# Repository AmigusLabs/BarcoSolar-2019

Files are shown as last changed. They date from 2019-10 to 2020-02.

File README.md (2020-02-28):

# BarcoSolar-2019
Barco solar Regata Marine Instruments 2019




Ver proyecto en [Amigus Labs](http://www.amiguslabs.org/portfolio_page/amigus-labs-barco-solar19/)

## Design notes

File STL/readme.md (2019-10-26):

Sec 1 - Soporte No, Relleno 15% — 10:00Horas  240g 

Sec 2 - Soporte Si, Relleno 20% — 19:34Horas  453g

Sec 3 - Soporte No, Relleno 15% — 18:30Horas  340g

Sec 4 - Soporte Si, Relleno 20% — 12:30Horas  268g.

Sec 5 - Soporte Si, Relleno 15% — 11:14Horas  219g

Sec 6 - Soporte NO, Relleno 15% — 13:13Horas  266g 

Sec 7 - Soporte NO, Relleno 15% — 8:05Horas  160g

Sec 8 - Soporte NO, Relleno 15% — 5:15Horas  126g

Sec 9 - Soporte NO, Relleno 15% — 4:45Horas  113g

Sec 10 - Soporte NO, Relleno 15% — 2:36Horas  61g

Soporte Balsas - Soporte No, Relleno 15% — 6:03Horas 146g (total 7:23)

Balsa 1 IZQ- Soporte No, Relleno 15% — 6:04Horas 142g  (total 7:40)

Balsa 2 IZQ- Soporte No, Relleno 15% — 5:34 Horas 127g

Balsa 3 IZQ- Soporte No, Relleno 15% — 1:12Horas 28g

Balsa 1 DER- Soporte No, Relleno 15% — 6:04Horas 142g

Balsa 2 DER- Soporte No, Relleno 15% — 5:37 Horas 127g

Balsa 3 DER- Soporte No, Relleno 15% — 1:12Horas 28g

Aletas - Soporte No, Relleno 20% — 1:42Horas 38g

Tapa_barco - Soporte No, Relleno 20% — 3:05Horas 78g

Soporte Servo - Soporte No, Relleno 15% — 0:38Horas 15g

Soporte Arduino - Soporte No, Relleno 15% — 1:08Horas 35g

Soporte Motor PLA - Soporte No, Relleno 15% — 1:00Horas 22g

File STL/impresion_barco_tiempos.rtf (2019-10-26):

Xxx Sec 1 - Soporte No, Relleno 15% — 10:00Horas 240g — pendiente diseño
Xxx Sec 2 - Soporte Si, Relleno 20% — 19:34Horas 453g
Xxx Sec 3 - Soporte No, Relleno 15% — 18:30Horas 340g
Xxx Sec 4 - Soporte Si, Relleno 20% — 12:30Horas 268g.
Xxx Sec 5 - Soporte Si, Relleno 15% — 11:14Horas 219g
Xxx Sec 6 - Soporte NO, Relleno 15% — 13:13Horas 266g
Xxx Sec 7 - Soporte NO, Relleno 15% — 8:05Horas 160g
Xxx Sec 8 - Soporte NO, Relleno 15% — 5:15Horas 126g
Xxx Sec 9 - Soporte NO, Relleno 15% — 4:45Horas 113g
Xxx Sec 10 - Soporte NO, Relleno 15% — 2:36Horas 61g

Xxx Soporte Balsas - Soporte No, Relleno 15% — 6:03Horas 146g (total 7:23)

Xxx Balsa 1 IZQ- Soporte No, Relleno 15% — 6:04Horas 142g (total 7:40)
Xxx Balsa 2 IZQ- Soporte No, Relleno 15% — 5:34 Horas 127g
Xxx Balsa 3 IZQ- Soporte No, Relleno 15% — 1:12Horas 28g

Xxx Balsa 1 DER- Soporte No, Relleno 15% — 6:04Horas 142g
Xxx Balsa 2 DER- Soporte No, Relleno 15% — 5:37 Horas 127g
Xxx Balsa 3 DER- Soporte No, Relleno 15% — 1:12Horas 28g

Xxx Aletas - Soporte No, Relleno 20% — 1:42Horas 38g

Xxxx Tapa_barco - Soporte No, Relleno 20% — 3:05Horas 78g
Xxx Soporte Servo - Soporte No, Relleno 15% — 0:38Horas 15g
Xxx Soporte Arduino - Soporte No, Relleno 15% — 1:08Horas 35g
Xxx Soporte Motor PLA - Soporte No, Relleno 15% — 1:00Horas 22g

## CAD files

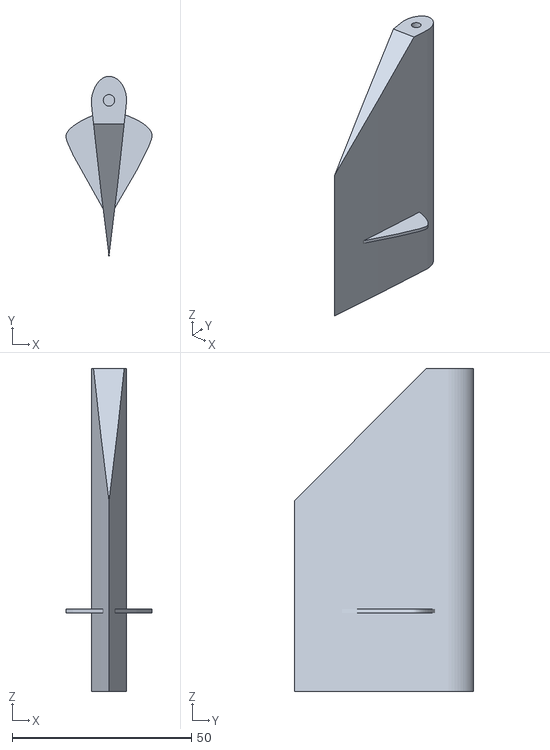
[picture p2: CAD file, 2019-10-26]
STL/timon1.stl
24.0 x 49.9 x 90.0

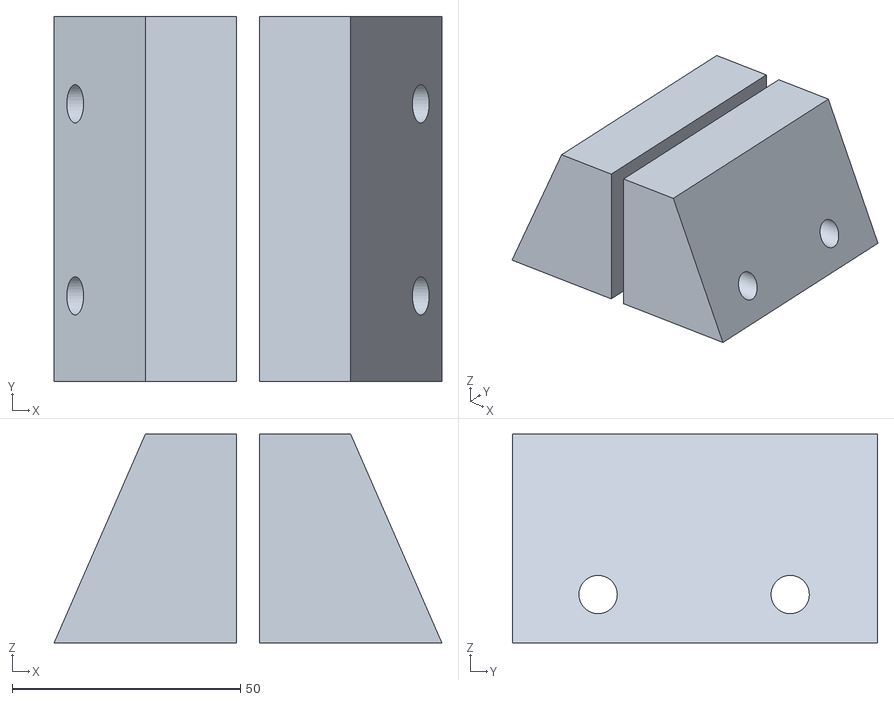
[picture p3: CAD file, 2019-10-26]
STL_Soporte/soporte_abajo.stl
85.0 x 80.0 x 45.7

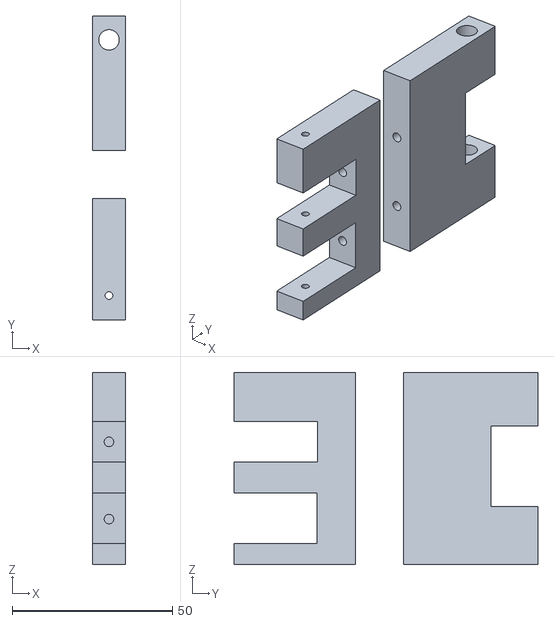
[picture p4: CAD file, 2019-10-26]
STL/timon_demo.stl
10.2 x 94.9 x 60.0

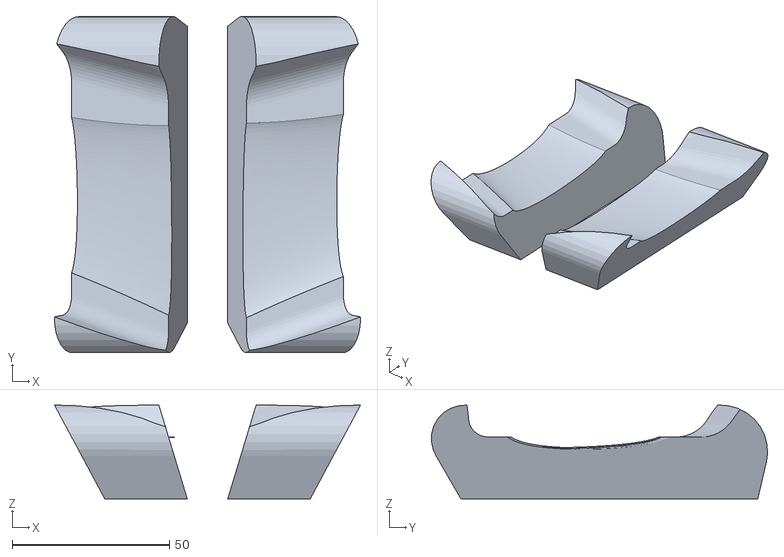
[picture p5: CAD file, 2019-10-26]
STL_Soporte/soporte_brazos2.stl
97.4 x 107.0 x 29.8

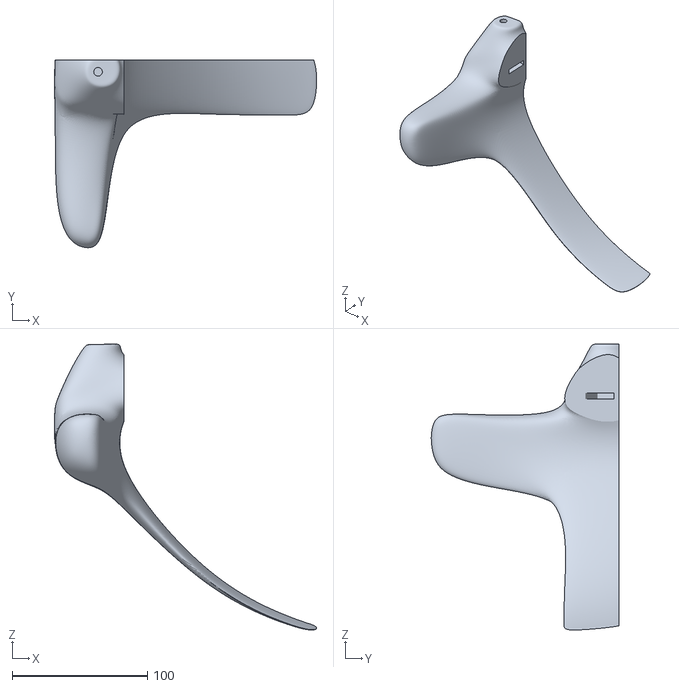
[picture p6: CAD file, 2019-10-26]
STL/soporte_balsa_der_1.stl
194.1 x 138.8 x 211.6

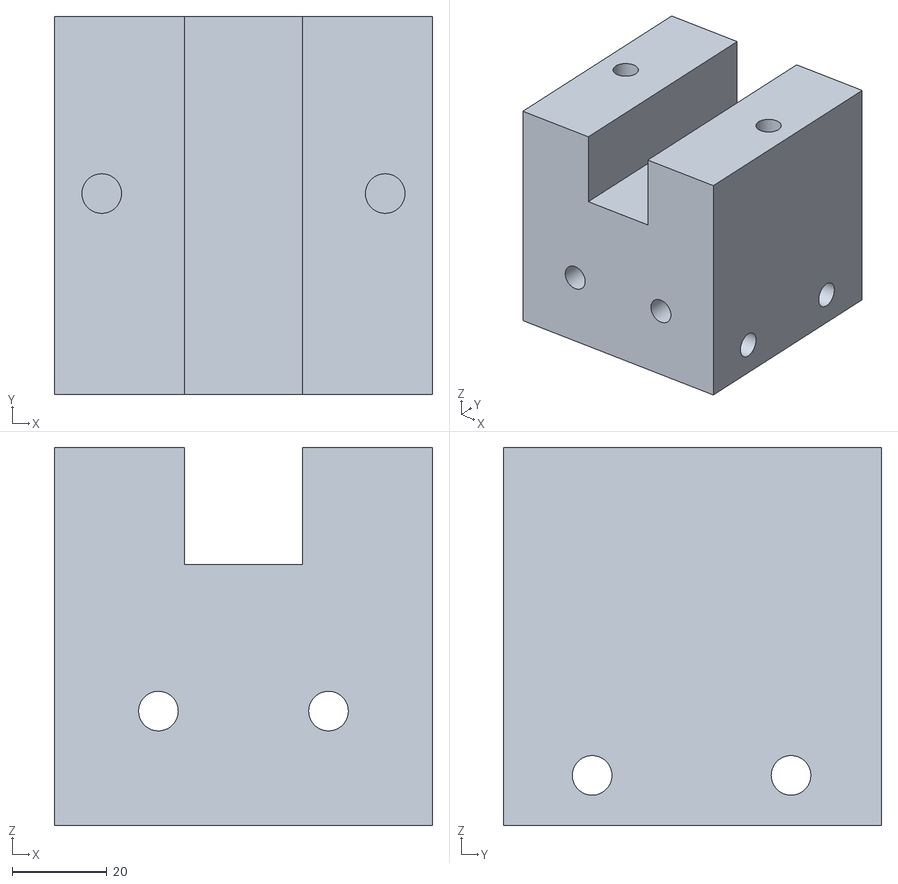
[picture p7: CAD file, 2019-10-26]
STL_Soporte/soporte_medio.stl
80.0 x 80.0 x 80.0

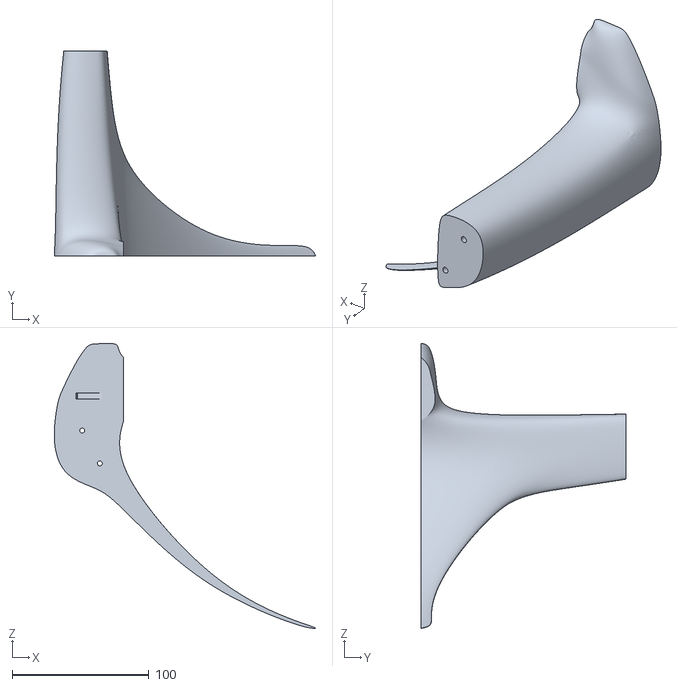
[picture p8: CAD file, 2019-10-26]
STL/soporte_balsa_der_2.stl
191.2 x 150.0 x 208.4

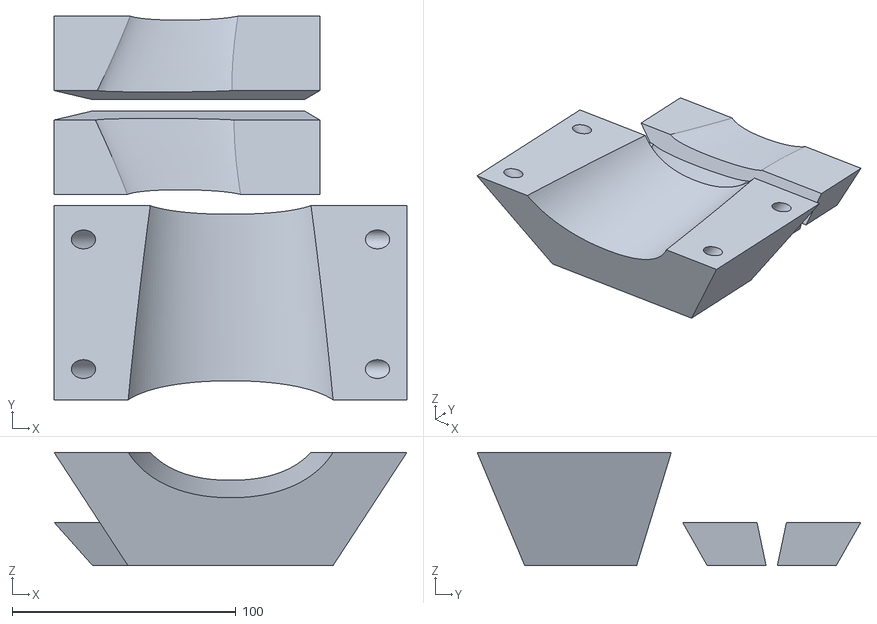
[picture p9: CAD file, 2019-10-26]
STL_Soporte/soporte_nuevo.stl
157.7 x 171.4 x 50.6

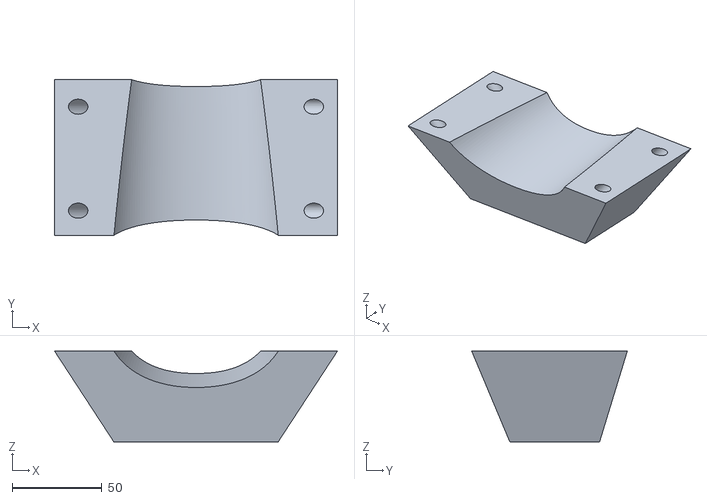
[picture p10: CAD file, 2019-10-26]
STL_Soporte/soporte_arriba.stl
157.7 x 86.7 x 50.6

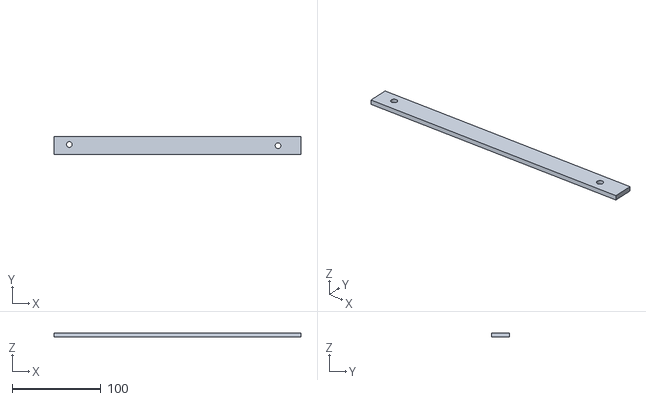
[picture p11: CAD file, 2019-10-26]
STL/Aluminio_soporte_balsas.stl
278.1 x 20.5 x 4.51

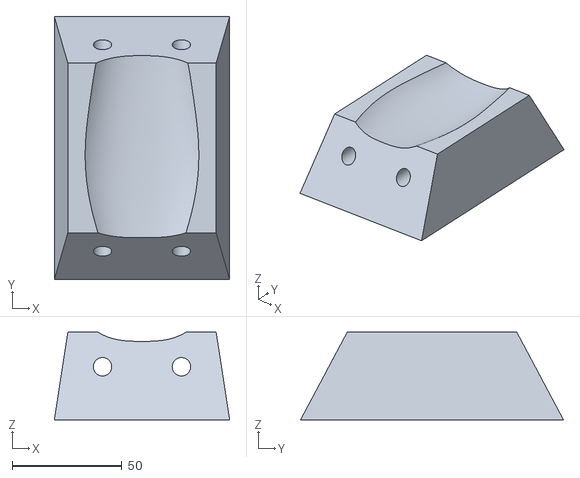
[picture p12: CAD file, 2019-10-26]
STL_Soporte/soporte_atras.stl
80.0 x 120.0 x 40.0

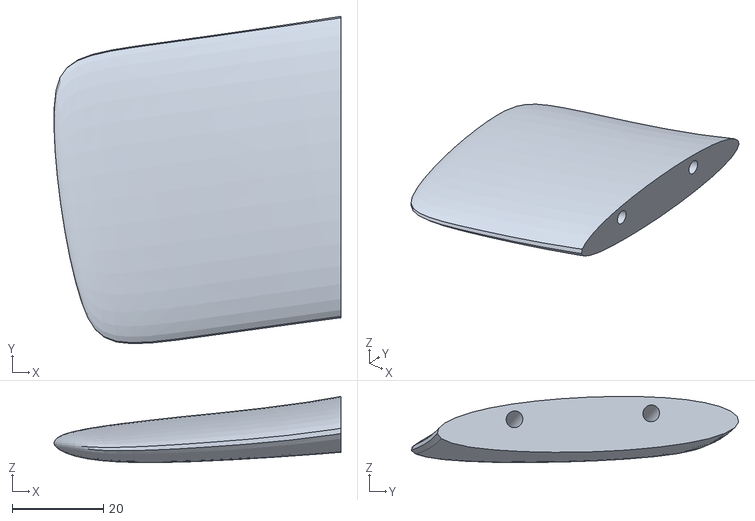
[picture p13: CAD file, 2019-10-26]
STL/sec_aleta_der.stl
63.1 x 71.9 x 14.5

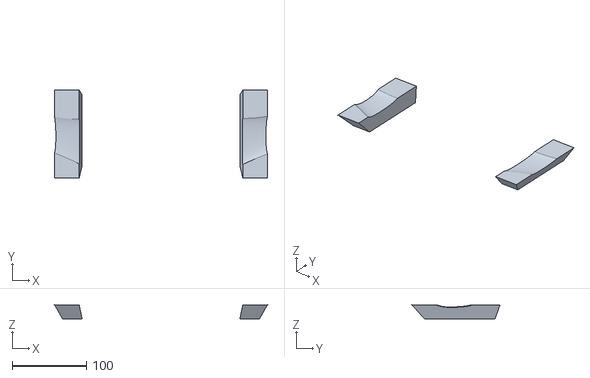
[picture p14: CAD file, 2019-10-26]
STL_Soporte/soporte_brazos.stl
286.7 x 118.8 x 19.4

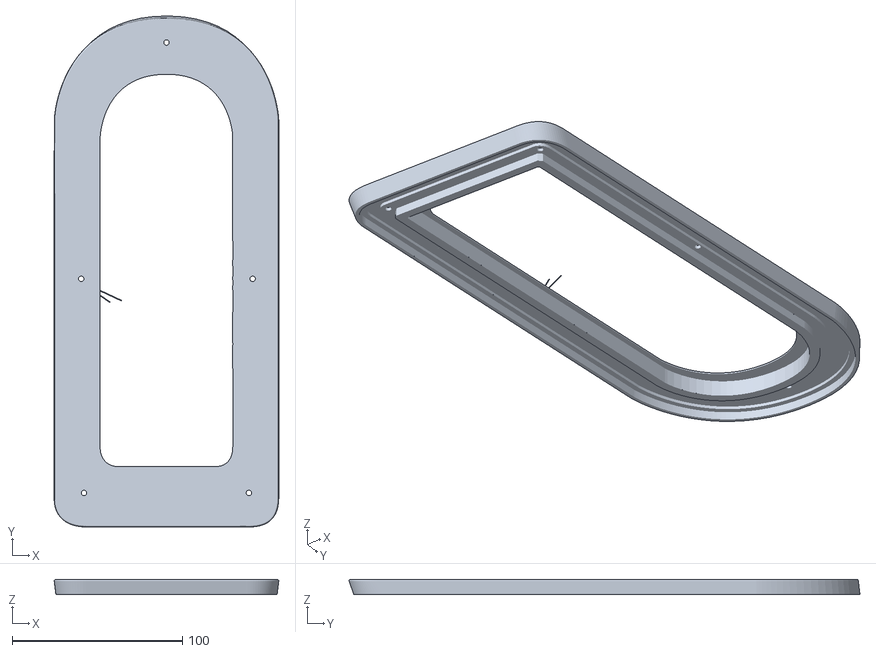
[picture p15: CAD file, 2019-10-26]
STL/tapa_barco3_bien.stl
132.0 x 300.4 x 9.02

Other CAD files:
STL/soporte_balsa_izq_2.stl
STL/sec6.stl
STL/soporte_servo.stl
STL/sec8.stl
STL/eje_timon.stl
STL/eje_y_timon.stl
STL/sec1.stl
STL/sec10.stl
STL/sec4.stl
STL/sec5.stl
STL/sec6_soporte.stl
STL/sec7.stl
STL/sec9.stl
STL/sec_aleta_izq.stl
STL/soporte_arduino.stl
STL/soporte_balsa_der.stl
STL/soporte_balsa_der_3.stl
STL/soporte_balsa_izq.stl
STL/soporte_balsa_izq_1.stl
STL/soporte_balsa_izq_3.stl
STL/soporte_motor_PLA.stl
STL/tapa_barco.stl
STL/timon2.stl

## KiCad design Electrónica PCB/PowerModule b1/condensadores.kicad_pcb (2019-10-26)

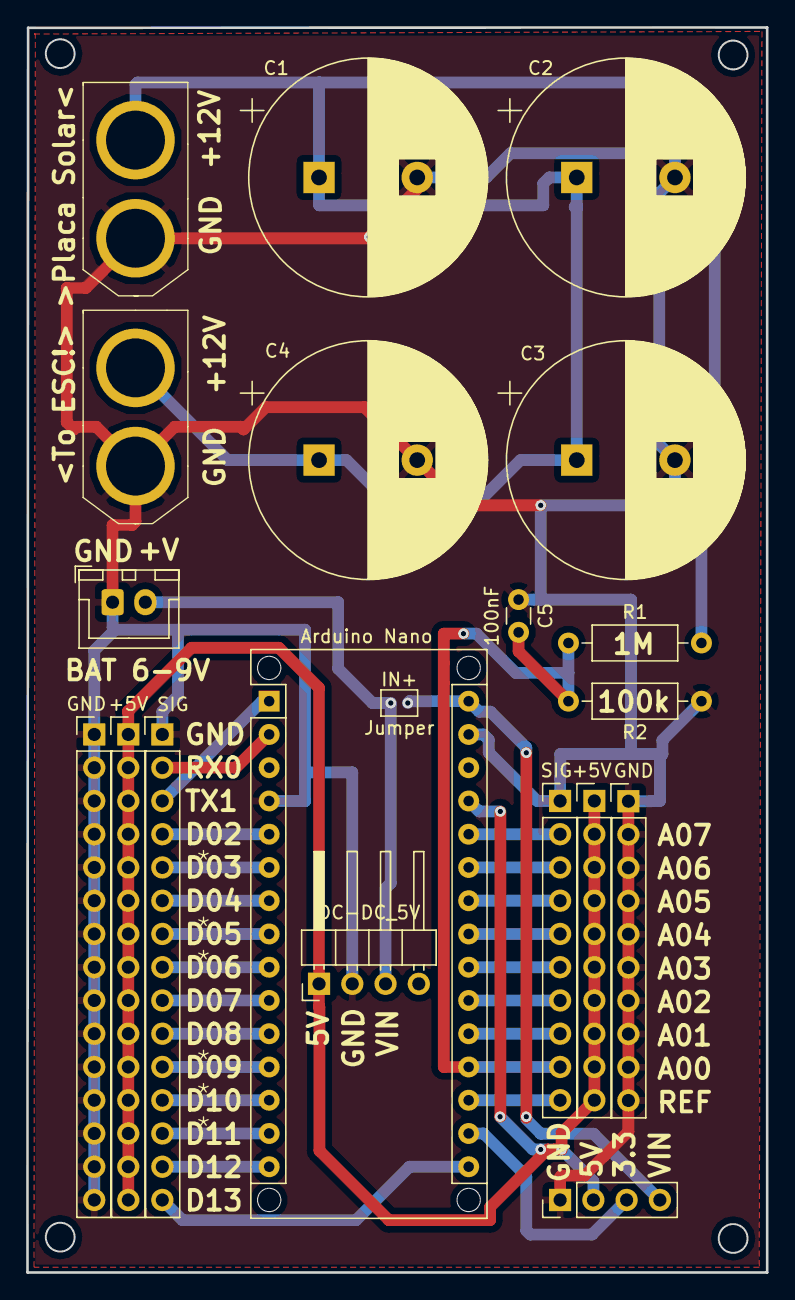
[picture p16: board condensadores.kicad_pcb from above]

Board: 2 copper layers, 56.5 x 95.1 mm, 20 parts (0 on the bottom side), 28 nets.

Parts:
+5V: +5V; PinHeader_1x15_P2.54mm_Vertical
+5V#2: +5V; PinHeader_1x10_P2.54mm_Vertical
Arduino Nano: Arduino_Nano_v3.x; Arduino_Nano_WithMountingHoles
C1, C2, C3, C4: 35V4700uF; CP_Radial_D18.0mm_P7.50mm
C5: 100nF; C_Disc_D3.0mm_W1.6mm_P2.50mm
DC-DC_5V: DC-DC; PinHeader_1x04_P2.54mm_Horizontal
GND: GND; PinHeader_1x15_P2.54mm_Vertical
GND#2: GND; PinHeader_1x10_P2.54mm_Vertical
IN+: Jumper; SolderJumper-2_P1.3mm_Open_Pad1.0x1.5mm
J1, J1#2: Placa Solar +12V; XT60
J3: BAT 6-9V; JST_XH_B02B-XH-A_1x02_P2.50mm_Vertical
JA3: SIG 3; PinHeader_1x04_P2.54mm_Vertical
R1: 1M; R_Axial_DIN0207_L6.3mm_D2.5mm_P10.16mm_Horizontal
R2: 100K; R_Axial_DIN0207_L6.3mm_D2.5mm_P10.16mm_Horizontal
SIG: SIG; PinHeader_1x15_P2.54mm_Vertical
SIG#2: SIG; PinHeader_1x10_P2.54mm_Vertical

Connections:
+5V: +5V.1, +5V.2, +5V.3, +5V.4, +5V.5, +5V.6, +5V.7, +5V.8, +5V.9, +5V.10, +5V.11, +5V.12, +5V.13, +5V.14, +5V.15, +5V#2.1, +5V#2.2, +5V#2.3, +5V#2.4, +5V#2.5, +5V#2.6, +5V#2.7, +5V#2.8, +5V#2.9, +5V#2.10, Arduino Nano.27, DC-DC_5V.1, JA3.2
/+12V: C1.1, C2.1, C3.1, C4.1, J1.2, J1#2.2, R1.2
A0: Arduino Nano.19, C5.2, R1.1, R2.2, SIG#2.9
GND: Arduino Nano.4, Arduino Nano.29, C1.2, C2.2, C3.2, C4.2, C5.1, DC-DC_5V.2, GND.1, GND.2, GND.3, GND.4, GND.5, GND.6, GND.7, GND.8, GND.9, GND.10, GND.11, GND.12, GND.13, GND.14, GND.15, GND#2.1, GND#2.2, GND#2.3, GND#2.4, GND#2.5, GND#2.6, GND#2.7, GND#2.8, GND#2.9, GND#2.10, J1.1, J1#2.1, J3.1, JA3.1, R2.1, SIG.1, SIG#2.1
IN+: Arduino Nano.30, DC-DC_5V.3, IN+.1, IN+.2, J3.2, JA3.4
unnamed: Arduino Nano.1, SIG.3
unnamed: Arduino Nano.2, SIG.2
unnamed: Arduino Nano.5, SIG.4
unnamed: Arduino Nano.6, SIG.5
unnamed: Arduino Nano.7, SIG.6
unnamed: Arduino Nano.8, SIG.7
unnamed: Arduino Nano.9, SIG.8
unnamed: Arduino Nano.10, SIG.9
unnamed: Arduino Nano.11, SIG.10
unnamed: Arduino Nano.12, SIG.11
unnamed: Arduino Nano.13, SIG.12
unnamed: Arduino Nano.14, SIG.13
unnamed: Arduino Nano.15, SIG.14
unnamed: Arduino Nano.16, SIG.15
unnamed: Arduino Nano.17, JA3.3
unnamed: Arduino Nano.18, SIG#2.10
unnamed: Arduino Nano.20, SIG#2.8
unnamed: Arduino Nano.21, SIG#2.7
unnamed: Arduino Nano.22, SIG#2.6
unnamed: Arduino Nano.23, SIG#2.5
unnamed: Arduino Nano.24, SIG#2.4
unnamed: Arduino Nano.25, SIG#2.3
unnamed: Arduino Nano.26, SIG#2.2

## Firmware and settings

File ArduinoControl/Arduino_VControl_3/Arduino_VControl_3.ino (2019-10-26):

#include <Servo.h>

#include <EEPROM.h>
#include <U8g2lib.h>
#include "HX711.h"
#include <Wire.h>


#include "Adafruit_SI1145.h"
Adafruit_SI1145 uv = Adafruit_SI1145();

const int LOADCELL_DOUT_PIN = 3;
const int LOADCELL_SCK_PIN = 4;

U8G2_SSD1306_128X64_NONAME_1_HW_I2C u8g2(U8G2_R0, /* reset=*/ U8X8_PIN_NONE);
HX711 scale;

float calibration_factor = 105246 ; // lectura calibracion / kg -//- 1Kg = 1000g    // 68200/0.648
float romread = 0;
const byte interruptPin = 2;
int taremoi = 1;


float Visindex ;
float IRindex ;
float UVindex ;



Servo ESC;
int Receptor_CH3 = A1;
int Receptor_CH5 = A2;
int vel_real = 0;
int vAhora_real = 0;
float Varduino = 4.8; // valor real de la alimentacion de Arduino, Vcc
float R1 = 1000000; // 1M
float R2 = 100000; // 100K

float peso = 0;

float Vfinal = 0;
int velocidad = 1000;
int vAhora = 1000;
int velmin = 1000;
int incremento = 20;
int voltage_max = 12.5;

int iteraciones_escritura = 10;
int escribe = 0;

const int lecturas = 5; // Total lecturas V
int index             = 0; // El indice de la lectura actual
float readings[lecturas]; // Lecturas de la entrada analogica
float Vtotal           = 0.0; // Total
float Vmedia         = 0.0; // Promedio

float Ptotal;
float peso_media[lecturas]; // Lecturas de peso

void setup() {

  u8g2.begin();

  Serial.begin(9600);

  scale.begin(LOADCELL_DOUT_PIN, LOADCELL_SCK_PIN);
  
  if (! uv.begin()) {
    Serial.println("Didn't find Si1145");
    //  while (1);
  }


  u8g2.firstPage();
  do {
    u8g2.setFont(u8g2_font_logisoso16_tr);
    u8g2.drawStr(5, 38, "@migus Labs");
    u8g2.setFont(u8g2_font_helvR08_tr);
    u8g2.drawStr(18, 52, "Power Module v0.1");

  } while ( u8g2.nextPage() );

  delay(300);
  EEPROM.get( 0, romread );
  if (romread == romread) {
    calibration_factor = romread;
  }

  scale.set_scale();
  pinMode(interruptPin, INPUT_PULLUP);
  attachInterrupt(digitalPinToInterrupt(interruptPin), tare, CHANGE);
  long zero_factor = scale.read_average(); //Get a baseline reading




  pinMode(Receptor_CH3, INPUT);
  pinMode(Receptor_CH5, INPUT);

  Serial.print("Voltaje Máximo: ");
  Serial.print((int)(Varduino / (R2 / (R1 + R2))));
  Serial.println("V");
  Serial.println("");

  ESC.attach(10);  // salida al ESC a D10

  //delay(2000);
}

void tare() {
  taremoi = 1;
}


float leerVoltaje() {
  float v = (analogRead(0) * Varduino) / 1024.0;
  return (v / (R2 / (R1 + R2)));
}

bool switchActivado() {
  int value = pulseIn(Receptor_CH5, HIGH);
  if (value > 1600) {
    return false;
  }
  return true;
}

void printSerial() {
  escribe++;
  if (escribe == iteraciones_escritura) {
    escribe = 0;
    Serial.print("Limitador activado:");    Serial.println(switchActivado());
    Serial.print("V: ");    Serial.println(Vfinal);
    Serial.print("Vel: ");    Serial.println(velocidad);
    Serial.print("vAhora: ");    Serial.println(vAhora);
    Serial.print("Fuerza: ");    Serial.print(peso);    Serial.println(" kg");
    Serial.print("Vis: "); Serial.println(Visindex);
    Serial.print("IR: "); Serial.println(IRindex);
    Serial.print("UV: ");  Serial.println(UVindex);
  }
}
void loop() {

  Vfinal = leerVoltaje();

  velocidad = pulseIn(Receptor_CH3, HIGH);

  if (Vfinal < voltage_max && vAhora >= velmin) {
    vAhora = vAhora - incremento;
  } else if (vAhora < velocidad) {
    vAhora = vAhora + incremento;
  } else {
    vAhora = velocidad;
  }

  vel_real = map(velocidad, 995, 1989, 0, 100 );
  vAhora_real = map(vAhora, 995, 1989, 0, 100 );
  if (vAhora_real < 0) {
    vAhora_real = 0;
  }
  if (vel_real < 0) {
    vel_real = 0;
  }

  if (taremoi != 0) {
    Serial.println("Calibrando Báscula");
    u8g2.firstPage();
    do {
      u8g2.setFont(u8g2_font_logisoso16_tr);
      u8g2.drawStr(5, 38, "@migus Labs");
      u8g2.setFont(u8g2_font_helvR08_tr);
      u8g2.drawStr(18, 52, "Power Module v0.1");
      u8g2.setFont(u8g2_font_helvR08_tr);
      u8g2.drawStr(32, 64, "Calibrando...");
    } while ( u8g2.nextPage() );
    delay(200);
    scale.tare(); //Reset the scale to 0
    delay(200);
    taremoi = 0;
  }

  scale.set_scale(calibration_factor); //Adjust to this calibration factor

  readings[index] = Vfinal;
  float peso_ahora =  scale.get_units();
  peso_media[index] = peso_ahora;

  index = index + 1;

  if (index >= lecturas) {
    index = 0;   // ...volvemos al inicio:
  }
  Vtotal = 0;
  Ptotal = 0;
  for (int i = 0; i <= lecturas; i++) {
    Vtotal = Vtotal + readings[i];
    Ptotal = Ptotal + peso_media[i];
  }

  Vmedia = Vtotal / lecturas;
  peso = Ptotal / lecturas; //



  if (peso < 0.09) {
    if (peso > -0.09) {
      peso = 0;
    }
  }



  String automatico;
  if (switchActivado()) {
    ESC.writeMicroseconds(vAhora);
    automatico = "A";
  } else {
    ESC.writeMicroseconds(velocidad);
    automatico = "M";

    vAhora_real = vel_real;



  }

  Visindex = uv.readVisible();
  IRindex = uv.readIR();
  UVindex = uv.readUV();
  UVindex /= 100.0;


  char g[10];
  dtostrf(peso, 5, 0, g);
  char vA[10];
  dtostrf(vAhora_real, 5, 0, vA);
  char vR[10];
  dtostrf(vel_real, 5, 0, vR);
  char vo[10];
  dtostrf(Vfinal, 5, 2, vo);
  char voM[10];
  dtostrf(Vmedia, 5, 2, voM);
  char Vis[10];
  dtostrf(Visindex, 5, 0 , Vis);
  char IR[10];
  dtostrf(IRindex, 5, 0, IR);
  char UV[10];
  dtostrf(UVindex, 5, 2, UV);

  u8g2.firstPage();
  do {
    u8g2.setFont(u8g2_font_helvR14_tr);
    u8g2.drawStr(14, 14, vA);
    u8g2.drawStr(60, 14, vR);
    u8g2.drawStr(14, 32, vo);
    u8g2.drawStr(80, 32, voM);
    u8g2.drawStr(58, 12, "/");
    u8g2.setFont(u8g2_font_helvB24_tr);
    u8g2.drawStr(48, 64, g);
    u8g2.setFont(u8g2_font_helvR08_tr);
    u8g2.drawStr(122, 62, "g");
    u8g2.drawStr(0, 12, "Vel:");
    u8g2.drawStr(0, 30, "V:");
    u8g2.drawStr(60, 30, "VM:");
    u8g2.drawStr(0, 44, "Vis:");
    u8g2.drawStr(0, 54, "IR:");
    u8g2.drawStr(0, 64, "UV:");
    u8g2.drawStr(20, 44, Vis); //Vis
    u8g2.drawStr(20, 54, IR); //IR
    u8g2.drawStr(20, 64, UV); //UV
    u8g2.setFont(u8g2_font_tenstamps_mf);

    if (automatico == "A") {
      u8g2.drawStr(110, 12, "A");
    } else {
      u8g2.drawStr(110, 12, "M");

    }

  } while ( u8g2.nextPage() );



  if (Serial.available())
  {
    char temp = Serial.read();
    if (temp == '+' || temp == 'a') {
      calibration_factor += 10;
      EEPROM.put(0, calibration_factor);
    } else if (temp == '-' || temp == 'z') {
      calibration_factor -= 10;
      EEPROM.put(0, calibration_factor);
    }
  }




  printSerial();
}

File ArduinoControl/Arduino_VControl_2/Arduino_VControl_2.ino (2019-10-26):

#include <Servo.h>




#include <SPI.h>
#include <Wire.h>



#include <Adafruit_GFX.h>
#include <Adafruit_SSD1306.h>





//#include <Fonts/FreeSans9pt7b.h>

#define SCREEN_WIDTH 128 // OLED display width, in pixels
#define SCREEN_HEIGHT 64 // OLED display height, in pixels

#define OLED_RESET     -1 // Reset pin # (or -1 if sharing Arduino reset pin)
Adafruit_SSD1306 display(SCREEN_WIDTH, SCREEN_HEIGHT, &Wire, OLED_RESET);
//Adafruit_SSD1306 display(SCREEN_WIDTH, SCREEN_HEIGHT, &Wire, OLED_RESET);


#include "HX711.h"


#define DOUT  3
#define CLK  4

HX711 balanza(DOUT, CLK);


Servo ESC;
int Receptor_CH3 = A1;
int Receptor_CH5 = A2;
int vel_real = 0;
int vAhora_real = 0;
float Varduino = 5; // valor real de la alimentacion de Arduino, Vcc
float R1 = 1000000; // 1M
float R2 = 100000; // 100K

float peso = 0;

float Vfinal = 0;
int velocidad = 1000;
int vAhora = 1000;
int velmin = 1000;
int incremento = 20;
int voltage_max = 12.5;

int iteraciones_escritura = 10;
int escribe = 0;

const int lecturas = 20; // Total lecturas V
int index             = 0; // El indice de la lectura actual
float readings[lecturas]; // Lecturas de la entrada analogica
float Vtotal           = 0.0; // Total
float Vmedia         = 0.0; // Promedio



void setup() {
  Serial.begin(9600);



  if (!display.begin(SSD1306_SWITCHCAPVCC, 0x3C)) { // Address 0x3D for 128x64
    Serial.println(F("SSD1306 allocation failed"));
    for (;;); // Don't proceed, loop forever
  }


  //display.begin(SSD1306_SWITCHCAPVCC, 0x3C);



  Serial.print("Lectura del valor del ADC:  ");
  Serial.println(balanza.read());
  Serial.println("No ponga ningun  objeto sobre la balanza");
  Serial.println("Destarando...");
  Serial.println("...");


  balanza.set_scale(119322); // Establecemos la escala
  balanza.tare(20);  //El peso actual es considerado Tara.

  Serial.println("Listo para pesar");




  display.clearDisplay();
  display.setTextSize(2); // Draw 2X-scale text
  display.setTextColor(WHITE);
  display.setCursor(12, 10);
  display.println(F("Amigus"));
  display.println(F("      Labs"));
  display.setCursor(15, 50);
  display.setTextSize(1);
  display.println(F("Power Module v0.1"));
  display.display();      // Show initial text


  pinMode(Receptor_CH3, INPUT);
  pinMode(Receptor_CH5, INPUT);

  Serial.print("Voltaje Máximo: ");
  Serial.print((int)(Varduino / (R2 / (R1 + R2))));
  Serial.println("V");
  Serial.println("");

  ESC.attach(10);  // salida al ESC a D10

  //delay(2000);
}

float leerVoltaje() {
  float v = (analogRead(0) * Varduino) / 1024.0;
  return (v / (R2 / (R1 + R2)));
}
bool switchActivado() {
  int value = pulseIn(Receptor_CH5, HIGH);
  if (value > 1600) {
    return false;
  }
  return true;
}
void printSerial() {
  escribe++;
  if (escribe == iteraciones_escritura) {
    escribe = 0;
    Serial.print("Limitador activado:");
    Serial.println(switchActivado());
    Serial.print("V: ");
    Serial.println(Vfinal);
    Serial.print("Vel: ");
    Serial.println(velocidad);
    Serial.print("vAhora: ");
    Serial.println(vAhora);
    Serial.print("Fuerza: ");
    //   Serial.print(peso);
    Serial.println(" kg");
  }
}
void loop() {

  Serial.print("--- 1 ---");
  Vfinal = leerVoltaje();

  velocidad = pulseIn(Receptor_CH3, HIGH);

  if (Vfinal < voltage_max && vAhora >= velmin) {
    vAhora = vAhora - incremento;
  } else if (vAhora < velocidad) {
    vAhora = vAhora + incremento;
  } else {
    vAhora = velocidad;
  }

  Serial.print("--- 2 ---");
  vel_real = map(velocidad, 995, 1989, 0, 10 );
  vAhora_real = map(vAhora, 995, 1989, 0, 10 );
  if (vAhora_real < 0) {
    vAhora_real = 0;
  }
  if (vel_real < 0) {
    vel_real = 0;
  }



  readings[index] = Vfinal;
  index = index + 1;

  if (index >= lecturas) {
    index = 0;   // ...volvemos al inicio:
  }
  Vtotal = 0;
  for (int i = 0; i <= lecturas; i++) {
    Vtotal = Vtotal + readings[i];
  }
  Vmedia = Vtotal / lecturas;


  String automatico;
  if (switchActivado()) {
    ESC.writeMicroseconds(vAhora);
    automatico = "A";
  } else {
    ESC.writeMicroseconds(velocidad);
    automatico = "M";

    vAhora_real = vel_real;



  }

  Serial.print("--- 3 ---");
  display.clearDisplay();
  display.setTextSize(2); // Draw 2X-scale text
  //display.setFont(&FreeSans9pt7b);
  display.setTextColor(WHITE);
  display.setCursor(0, 0);
  display.print(F("Vel:"));
  if (vAhora_real < 10) {
    display.print(F(" "));
  }
  display.print(vAhora_real);
  display.print(F("/"));
  if (vel_real < 10) {
    display.print(F(" "));
  }
  display.print(vel_real);
  display.println(automatico);
  display.print(F("Vol:"));
  if (Vfinal < 10) {
    display.print(F(" "));
  }
  display.println(Vfinal);

  display.print(F("VoM:"));
  if (Vmedia < 10) {
    display.print(F(" "));
  }
  display.println(Vmedia);

  display.print(F("P: "));


  //peso = balanza.get_units(20), 2;


  peso = balanza.get_value(10), 0;
  if (peso < 10) {
    display.print(F(" "));
  }
  if (peso < 100) {
    display.print(F(" "));
  }

  display.println(peso);

  display.display();      // Show initial text
  Serial.println("--- 4 ---");
  printSerial();
}
